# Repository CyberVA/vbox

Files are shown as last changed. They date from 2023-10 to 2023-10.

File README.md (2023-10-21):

# VBox: Low profile hitbox-layout fightstick

This repository is a fork of jfedor2's Flatbox project. Their original files are located in this repo [here](jfedor2_files).
You can also check our their repository [here](https://github.com/jfedor2/flatbox)

Changes from the original flatbox_rev4:
- Added RGB.
- Added OLED
- Relocated RP2040 and other various components for cosmetic reasons.

## PCB Image:

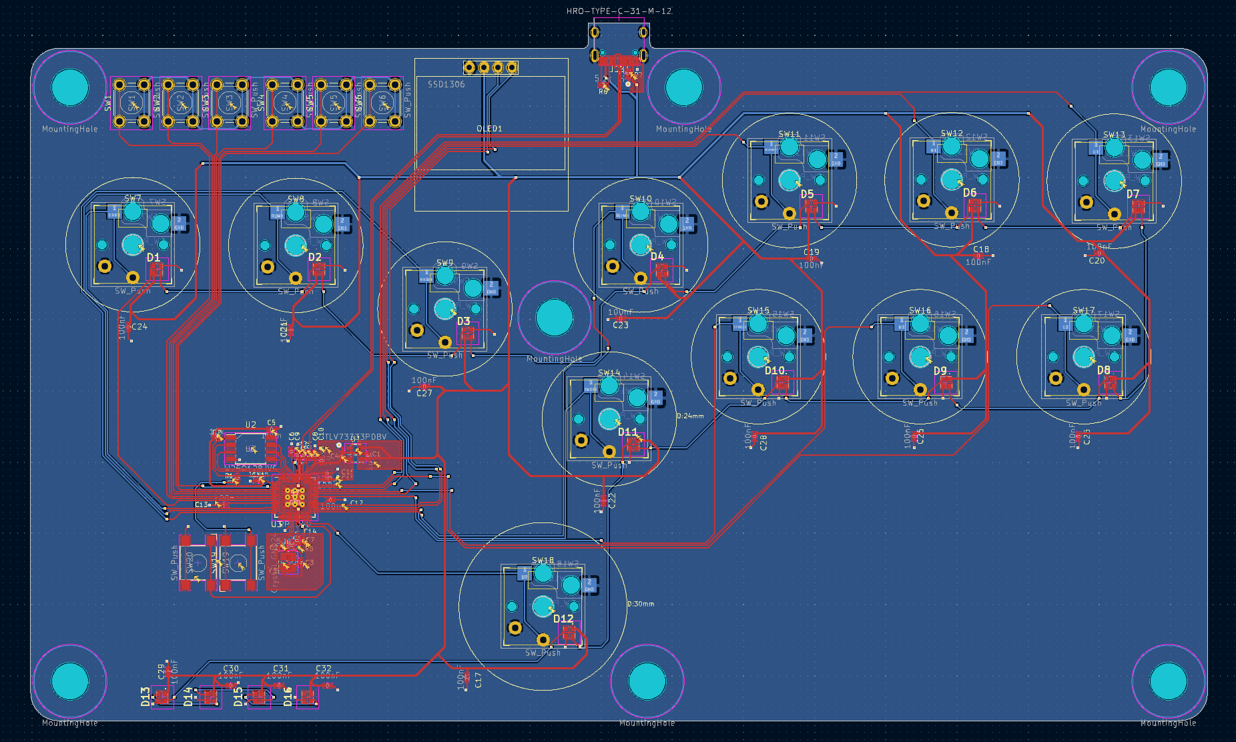
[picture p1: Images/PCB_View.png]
PCB View


## Schematic Images:

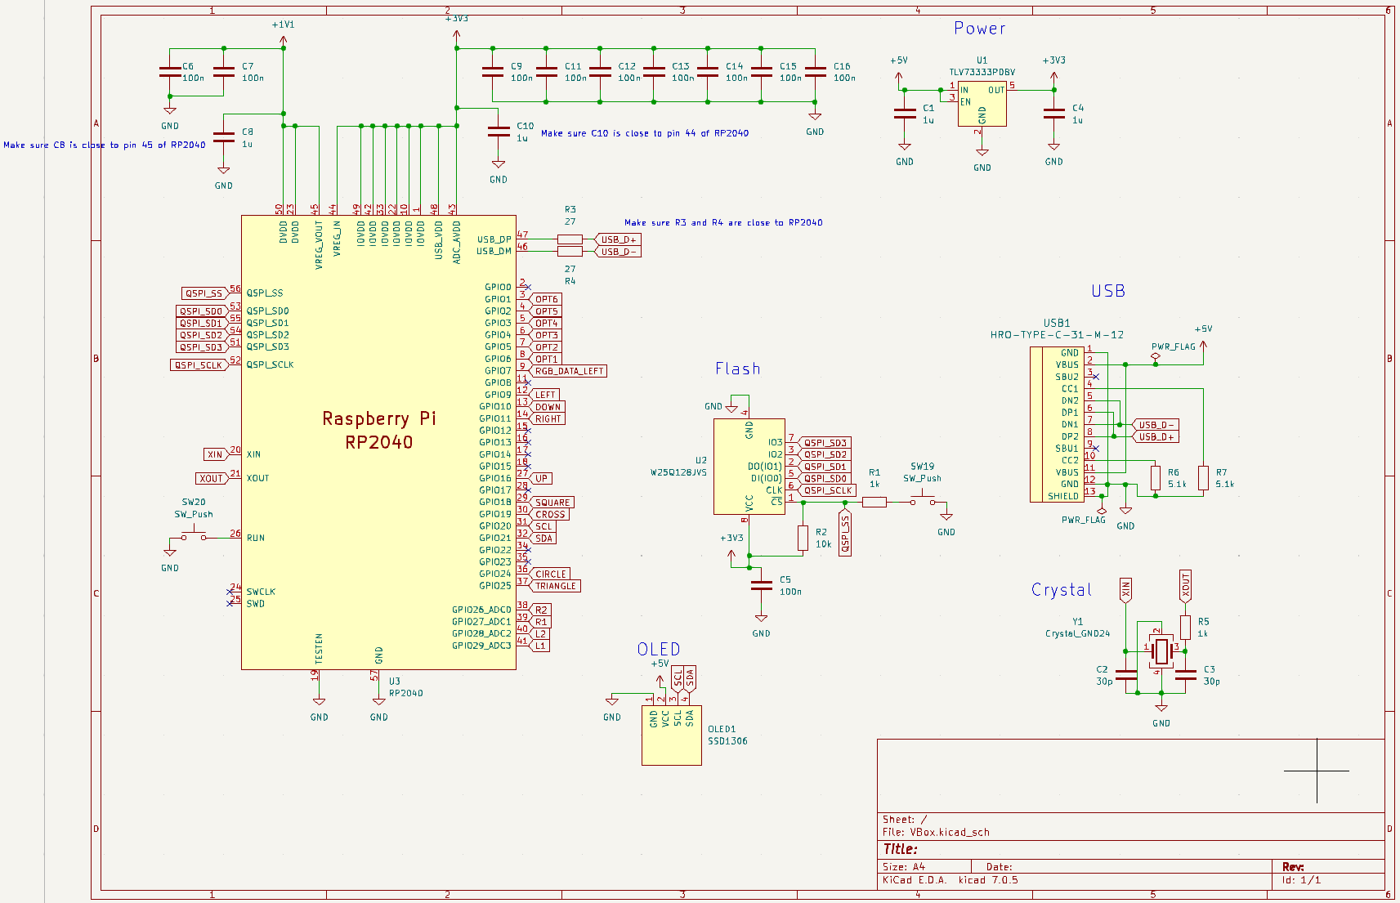
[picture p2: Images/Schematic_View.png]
Schematic


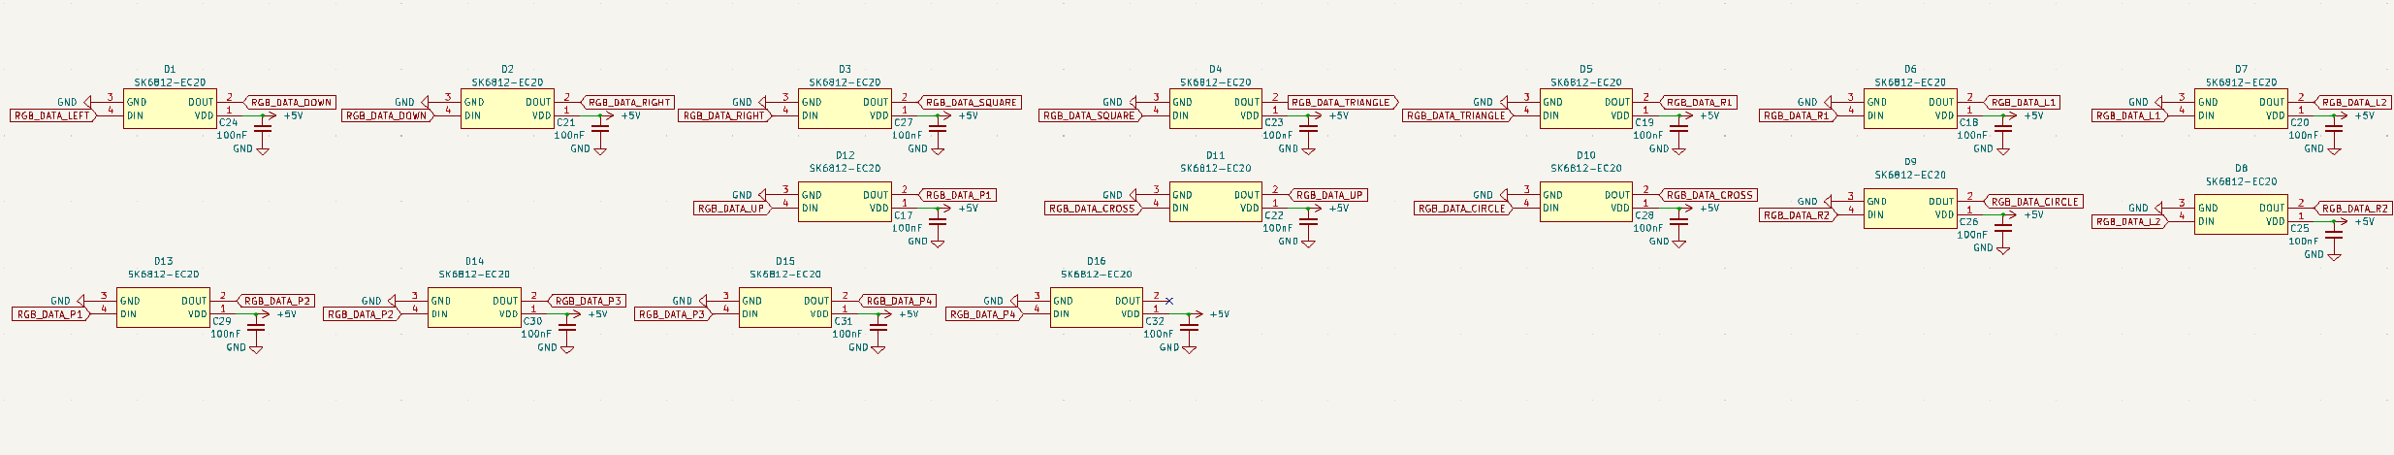
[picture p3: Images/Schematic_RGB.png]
Schematic RGB


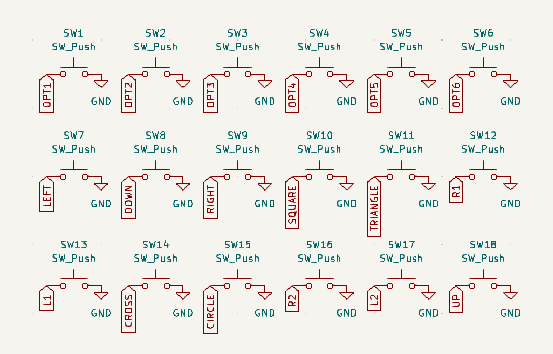
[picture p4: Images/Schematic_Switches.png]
Schematic Switches


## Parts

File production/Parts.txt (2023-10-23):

List of parts that cannot be placed by JLCPCB

Kailh PG1350 optional Hot Swap Sockets: https://chosfox.com/products/kailh-choc-switch-1350-hot-swap-sockets
 Sells for $1.45 for a pack of 10

SSD1306 I2C OLED: https://www.amazon.com/Dorhea-Display-SSD1306-Self-Luminous-Raspberry/dp/B0837DLWVH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
 Sells for $17.99 for a pack of 6

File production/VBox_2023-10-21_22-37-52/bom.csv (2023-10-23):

Designator | Footprint | Quantity | Value | LCSC Part #
C1, C10, C4, C8 | 0402 | 4 | 1u
C11, C12, C13, C14, C15, C16, C5, C6, C7, C9 | 0402 | 10 | 100n
C17, C18, C19, C20, C21, C22, C23, C24, C25, C26, C27, C28, C29, C30, C31, C32 | 0402 | 16 | 100nF | C52923
C2, C3 | 0402 | 2 | 30p
D1, D10, D11, D12, D13, D14, D15, D16, D2, D3, D4, D5, D6, D7, D8, D9 | SK6812EC20 | 16 | SK6812-EC20
H1, H2, H3, H4, H5, H6, H7 | MountingHole_6.4mm_M6 | 7 | MountingHole
OLED1 | 128x64OLED | 1 | SSD1306
R1, R5 | 0402 | 2 | 1k
R2 | 0402 | 1 | 10k
R3, R4 | 0402 | 2 | 27
R6, R7 | 0402 | 2 | 5.1k
SW1, SW2, SW3, SW4, SW5, SW6 | SW_PUSH_6mm_H5mm | 6 | SW_Push
SW10, SW11, SW12, SW13, SW14, SW15, SW16, SW17, SW18, SW7, SW8, SW9 | Kailh_socket_PG1350_optional | 12 | SW_Push
SW19, SW20 | SW_SPST_Omron_B3FS-100xP | 2 | SW_Push
U1 | SOT-23-5 | 1 | TLV73333PDBV
U2 | SOIC-8_5.23x5.23mm_P1.27mm | 1 | W25Q128JVS
U3 | RP2040-QFN-56 | 1 | RP2040
USB1 | HRO-TYPE-C-31-M-12-Assembly | 1 | HRO-TYPE-C-31-M-12
Y1 | Crystal_SMD_3225-4Pin_3.2x2.5mm | 1 | Crystal_GND24

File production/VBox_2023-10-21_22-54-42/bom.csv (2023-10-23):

Designator | Footprint | Quantity | Value | LCSC Part #
C1, C10, C4, C8 | 0402 | 4 | 1uF | C52923
C11, C12, C13, C14, C15, C16, C5, C6, C7, C9 | 0402 | 10 | 100nF | C1525
C17, C18, C19, C20, C21, C22, C23, C24, C25, C26, C27, C28, C29, C30, C31, C32 | 0402 | 16 | 100nF | C1525
C2, C3 | 0402 | 2 | 30pF | C1570
D1, D10, D11, D12, D13, D14, D15, D16, D2, D3, D4, D5, D6, D7, D8, D9 | SK6812EC20 | 16 | SK6812-EC20 | C2909058
OLED1 | 128x64OLED | 1 | SSD1306
R1, R5 | 0402 | 2 | 1k | C11702
R2 | 0402 | 1 | 10k | C25744
R3, R4 | 0402 | 2 | 27k | C138021
R6, R7 | 0402 | 2 | 5.1k | C25905
SW1, SW2, SW3, SW4, SW5, SW6 | SW_PUSH_6mm_H5mm | 6 | SW_Push | C428628
SW10, SW11, SW12, SW13, SW14, SW15, SW16, SW17, SW18, SW7, SW8, SW9 | Kailh_socket_PG1350_optional | 12 | SW_Push
SW19, SW20 | SW_SPST_Omron_B3FS-100xP | 2 | SW_Push | C271750
U1 | SOT-23-5 | 1 | TLV73333PDBV | C134139
U2 | SOIC-8_5.23x5.23mm_P1.27mm | 1 | W25Q128JVS | C97521
U3 | RP2040-QFN-56 | 1 | RP2040 | C2040
USB1 | HRO-TYPE-C-31-M-12-Assembly | 1 | HRO-TYPE-C-31-M-12 | C165948
Y1 | Crystal_SMD_3225-4Pin_3.2x2.5mm | 1 | Crystal_GND24 | C9002

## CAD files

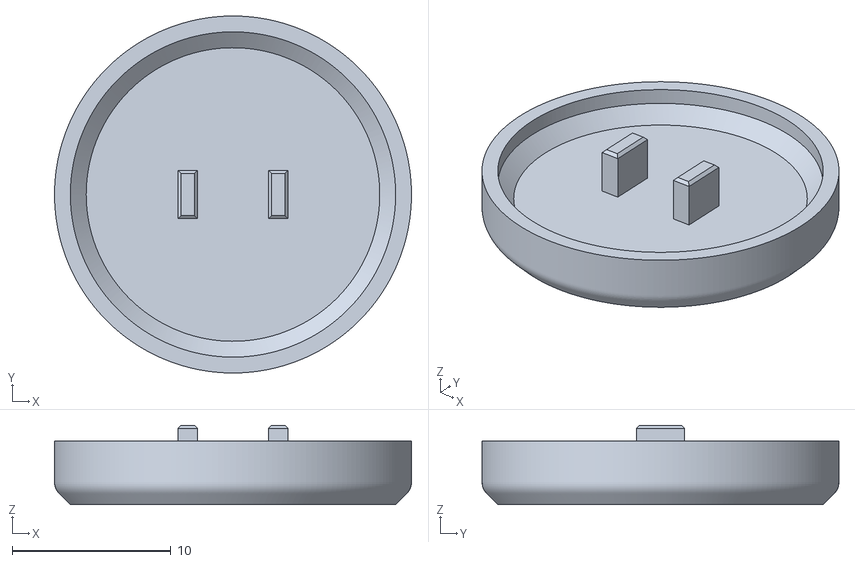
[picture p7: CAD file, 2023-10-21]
jfedor2_files/3d-printed-buttoncaps/Buttoncap.stl
22.5 x 22.5 x 5.00

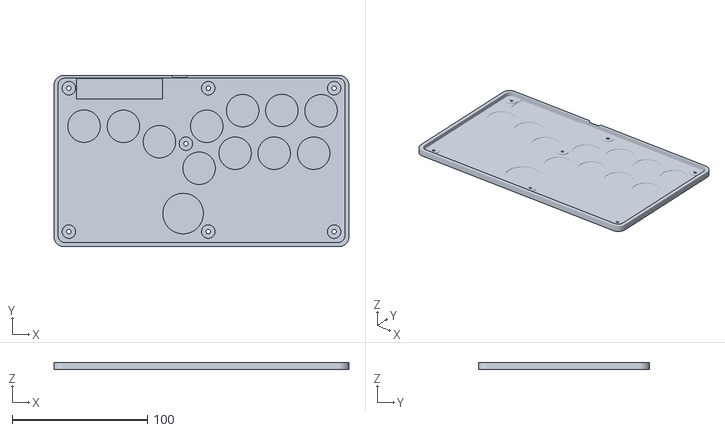
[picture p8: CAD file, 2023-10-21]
jfedor2_files/hardware-rev5/3d-printed-case/Flatbox-rev5-Bottom.stl
218.0 x 126.4 x 5.20

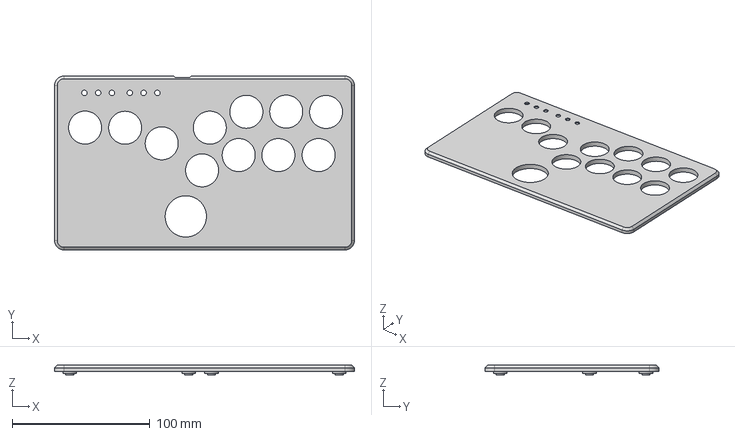
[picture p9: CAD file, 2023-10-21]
jfedor2_files/hardware-rev5/cnc-machined-case/Flatbox-rev5-CNC-Top.step
218.0 x 126.4 x 7.20 mm

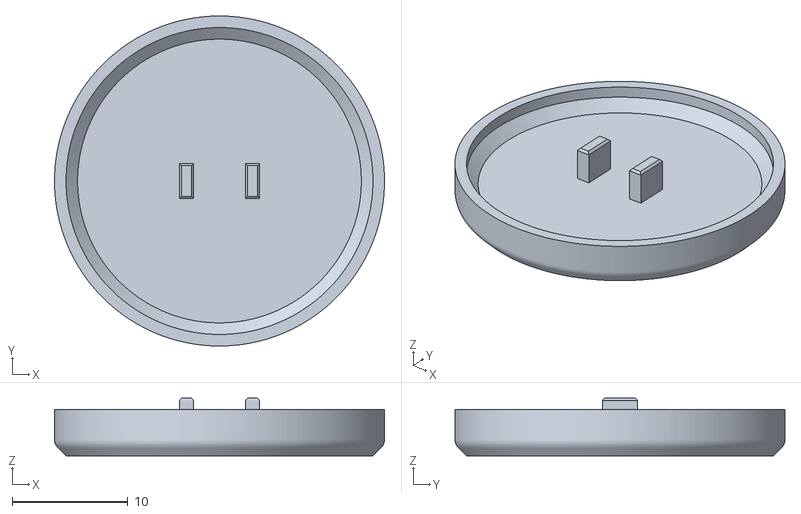
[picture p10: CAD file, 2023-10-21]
jfedor2_files/3d-printed-buttoncaps/ButtoncapBig.stl
28.5 x 28.5 x 5.00

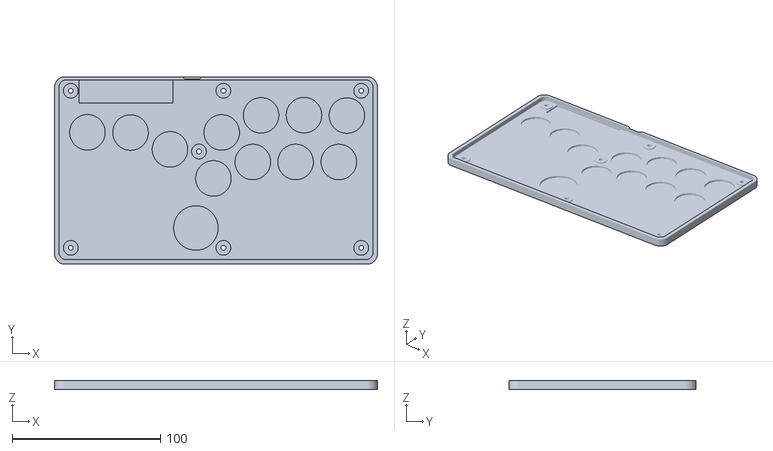
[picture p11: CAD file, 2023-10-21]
jfedor2_files/hardware-rev5/3d-printed-case/Flatbox-rev5-Bottom-hotswap.stl
218.0 x 126.4 x 6.20

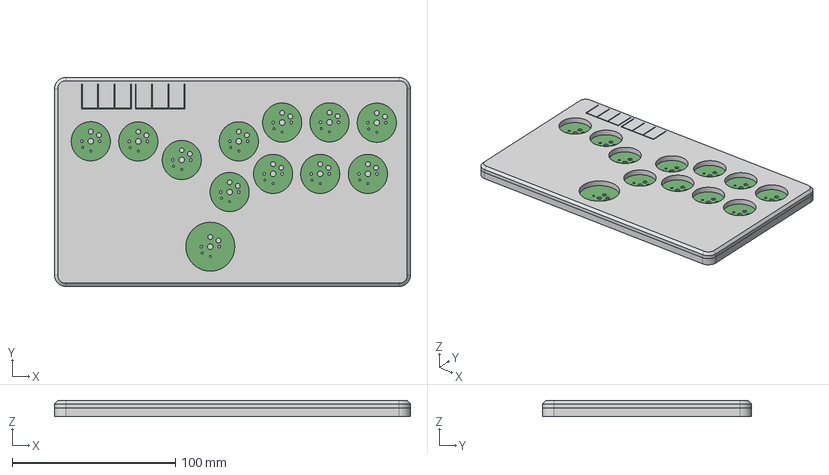
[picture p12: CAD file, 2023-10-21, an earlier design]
jfedor2_files/hardware-rev1.1/extras/Flatbox-rev1.1-case.step
218.0 x 128.0 x 9.80 mm

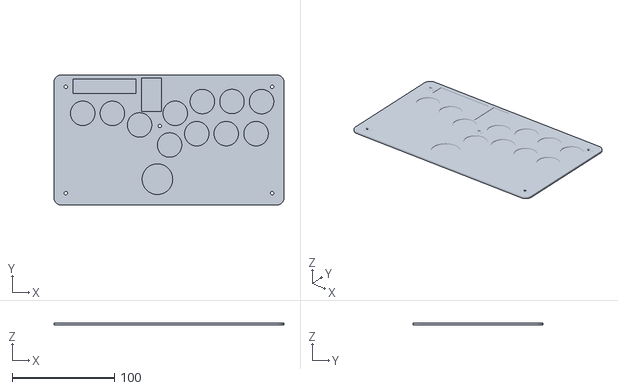
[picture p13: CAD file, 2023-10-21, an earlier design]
jfedor2_files/hardware-rev1/3d-printed-case/Flatbox-rev1b-Bottom.stl
225.2 x 127.4 x 2.20

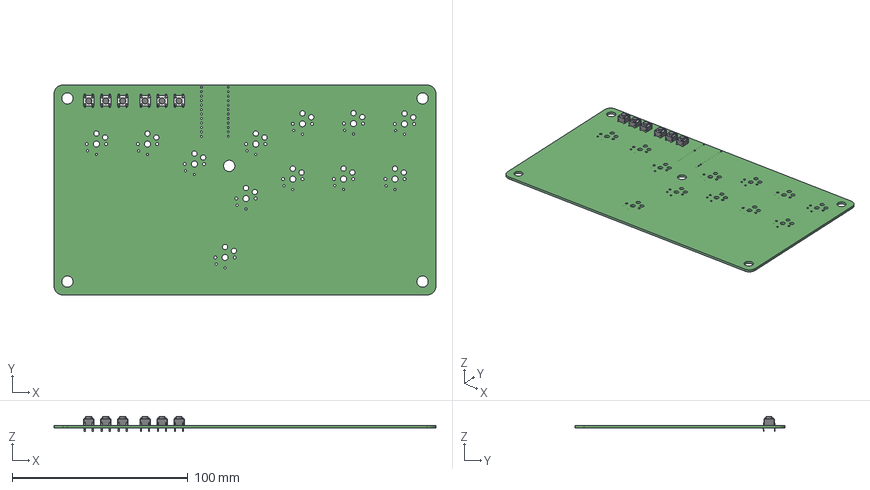
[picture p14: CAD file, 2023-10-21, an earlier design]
jfedor2_files/hardware-rev1/extras/Flatbox-rev1b-pcb.step
217.2 x 119.4 x 8.50 mm

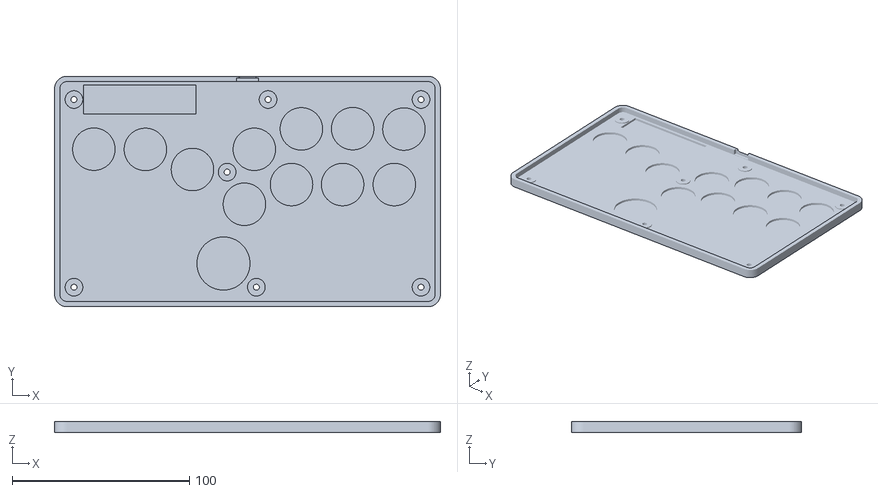
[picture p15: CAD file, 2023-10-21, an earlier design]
jfedor2_files/hardware-rev2/3d-printed-case/Flatbox-rev2b-Bottom-hotswap.stl
218.0 x 130.1 x 6.20

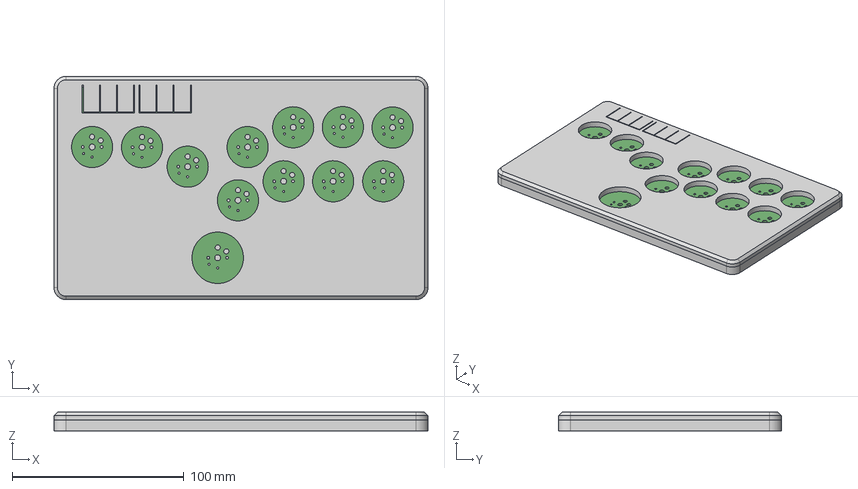
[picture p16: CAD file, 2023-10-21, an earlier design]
jfedor2_files/hardware-rev2/extras/Flatbox-rev2b-case-hotswap.step
218.0 x 130.1 x 10.8 mm

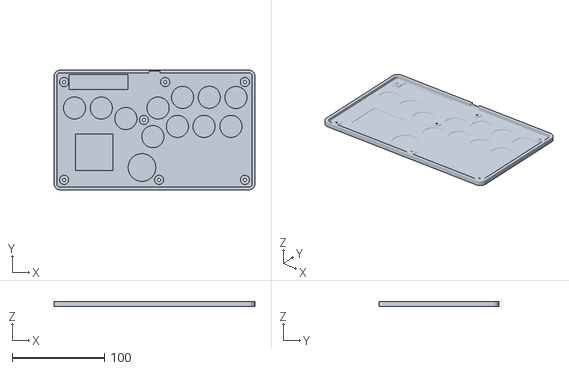
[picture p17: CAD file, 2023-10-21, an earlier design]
jfedor2_files/hardware-rev3/3d-printed-case/Flatbox-rev3-Bottom.stl
218.0 x 130.1 x 5.20

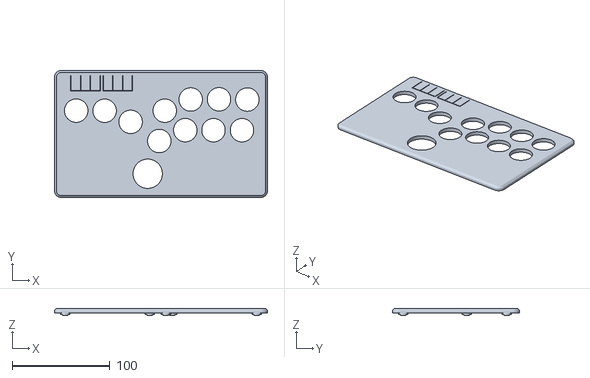
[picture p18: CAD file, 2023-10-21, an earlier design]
jfedor2_files/hardware-rev4/3d-printed-case/Flatbox-rev4-Top.stl
218.0 x 130.1 x 7.20

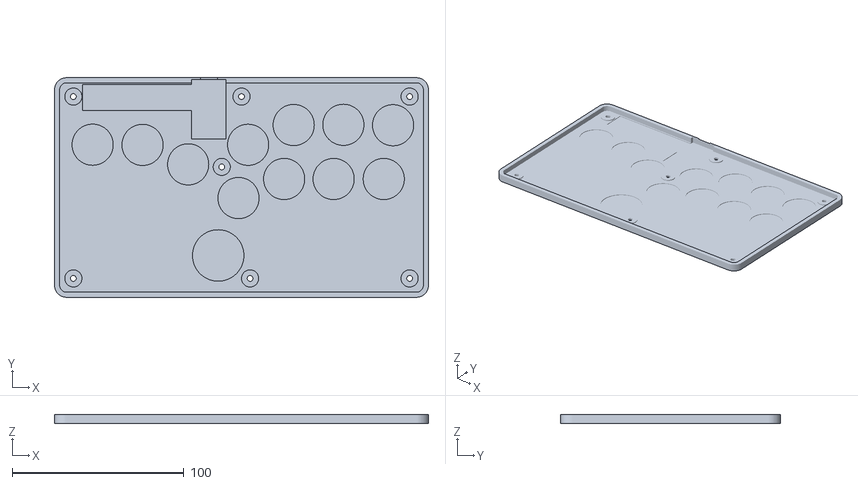
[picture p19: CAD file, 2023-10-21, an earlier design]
jfedor2_files/hardware-rev1.1/3d-printed-case/Flatbox-rev1.1-Bottom.stl
218.0 x 128.0 x 5.20

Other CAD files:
jfedor2_files/hardware-rev5/cnc-machined-case/Flatbox-rev5-CNC-Bottom.step
jfedor2_files/hardware-rev5/3d-printed-case/Flatbox-rev5-Top.stl
jfedor2_files/hardware-rev1.1/3d-printed-case/Flatbox-rev1.1-Top.stl
jfedor2_files/hardware-rev3/extras/Flatbox-rev3-case-hotswap.step
jfedor2_files/hardware-rev4/extras/Flatbox-rev4-case-hotswap.step
jfedor2_files/hardware-rev1.1/3d-printed-case/Flatbox-rev1.1-Bottom-hotswap.stl
jfedor2_files/hardware-rev1.1/extras/Flatbox-rev1.1-case-hotswap.step
jfedor2_files/hardware-rev1.1/extras/Flatbox-rev1.1-pcb.step
jfedor2_files/hardware-rev1/3d-printed-case/Flatbox-rev1b-Bottom-hotswap.stl
jfedor2_files/hardware-rev1/3d-printed-case/Flatbox-rev1b-Top.stl
jfedor2_files/hardware-rev2/3d-printed-case/Flatbox-rev2b-Bottom.stl
jfedor2_files/hardware-rev2/3d-printed-case/Flatbox-rev2b-Top.stl
jfedor2_files/hardware-rev2/extras/Flatbox-rev2b-case.step
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

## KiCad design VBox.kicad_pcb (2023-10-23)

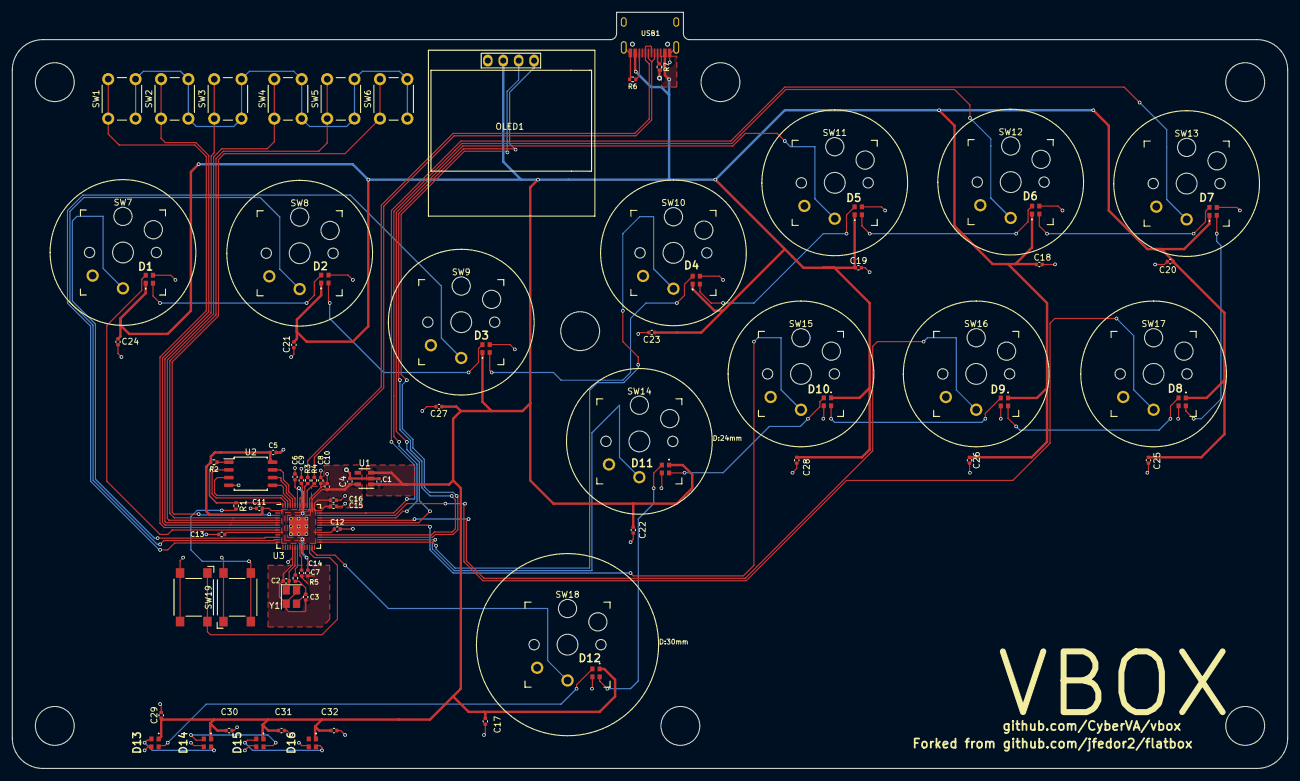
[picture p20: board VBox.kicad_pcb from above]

Board: 2 copper layers, 210.0 x 124.5 mm, 88 parts (0 on the bottom side), 57 nets.

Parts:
C1, C4, C8, C10: 1uF; C_0402_1005Metric
C2, C3: 30pF; C_0402_1005Metric
C5, C6, C7, C9, C11, C12, C13, C14, C15, C16, C17, C18, C19, C20, C21, C22, C23, C24, C25, C26, C27, C28, C29, C30, C31, C32: 100nF; C_0402_1005Metric
D1, D2, D3, D4, D5, D6, D7, D8, D9, D10, D11, D12, D13, D14, D15, D16: SK6812-EC20; SK6812EC20
H1, H2, H3, H4, H5, H6, H7: MountingHole; MountingHole_6.4mm_M6
OLED1: SSD1306; 128x64OLED
R1, R5: 1k; R_0402_1005Metric
R2: 10k; R_0402_1005Metric
R3, R4: 27; R_0402_1005Metric
R6, R7: 5.1k; R_0402_1005Metric
SW1, SW2, SW3, SW4, SW5, SW6: SW_Push; SW_PUSH_6mm_H5mm
SW7, SW8, SW9, SW10, SW11, SW12, SW13, SW14, SW15, SW16, SW17, SW18: SW_Push; Kailh_socket_PG1350_optional
SW19, SW20: SW_Push; SW_SPST_Omron_B3FS-100xP
U1: TLV73333PDBV; SOT-23-5
U2: W25Q128JVS; SOIC-8_5.23x5.23mm_P1.27mm
U3: RP2040; RP2040-QFN-56
USB1: HRO-TYPE-C-31-M-12; HRO-TYPE-C-31-M-12-Assembly
Y1: Crystal_GND24; Crystal_SMD_3225-4Pin_3.2x2.5mm

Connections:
+1V1: C6.1, C7.1, C8.1, U3.23 (DVDD), U3.45 (VREG_VOUT), U3.50 (DVDD)
+3V3: C4.1, C5.1, C9.1, C10.1, C11.1, C12.1, C13.1, C14.1, C15.1, C16.1, R2.2, U1.5 (OUT), U2.8 (VCC), U3.1 (IOVDD), U3.10 (IOVDD), U3.22 (IOVDD), U3.33 (IOVDD), U3.42 (IOVDD), U3.43 (ADC_AVDD), U3.44 (VREG_IN), U3.48 (USB_VDD), U3.49 (IOVDD)
+5V: C1.1, C17.1, C18.1, C19.1, C20.1, C21.1, C22.1, C23.1, C24.1, C25.1, C26.1, C27.1, C28.1, C29.1, C30.1, C31.1, C32.1, D1.1 (VDD), D2.1 (VDD), D3.1 (VDD), D4.1 (VDD), D5.1 (VDD), D6.1 (VDD), D7.1 (VDD), D8.1 (VDD), D9.1 (VDD), D10.1 (VDD), D11.1 (VDD), D12.1 (VDD), D13.1 (VDD), D14.1 (VDD), D15.1 (VDD), D16.1 (VDD), OLED1.2 (VCC), U1.1 (IN), U1.3 (EN), USB1.2 (VBUS), USB1.11 (VBUS)
CIRCLE: SW15.1, U3.36 (GPIO24)
CROSS: SW14.1, U3.30 (GPIO19)
DOWN: SW8.1, U3.13 (GPIO10)
GND: C1.2, C2.2, C3.2, C4.2, C5.2, C6.2, C7.2, C8.2, C9.2, C10.2, C11.2, C12.2, C13.2, C14.2, C15.2, C16.2, C17.2, C18.2, C19.2, C20.2, C21.2, C22.2, C23.2, C24.2, C25.2, C26.2, C27.2, C28.2, C29.2, C30.2, C31.2, C32.2, D1.3 (GND), D2.3 (GND), D3.3 (GND), D4.3 (GND), D5.3 (GND), D6.3 (GND), D7.3 (GND), D8.3 (GND), D9.3 (GND), D10.3 (GND), D11.3 (GND), D12.3 (GND), D13.3 (GND), D14.3 (GND), D15.3 (GND), D16.3 (GND), OLED1.1 (GND), R6.2, R7.2, SW1.2, SW2.2, SW3.2, SW4.2, SW5.2, SW6.2, SW7.2, SW8.2, SW9.2, SW10.2, SW11.2, SW12.2, SW13.2, SW14.2, SW15.2, SW16.2, SW17.2, SW18.2, SW19.2, SW20.1, U1.2 (GND), U2.4 (GND), U3.19 (TESTEN), U3.57 (GND), USB1.1 (GND), USB1.12 (GND), USB1.13 (SHIELD), Y1.2, Y1.4
L1: SW13.1, U3.41 (GPIO29_ADC3)
L2: SW17.1, U3.40 (GPIO28_ADC2)
LEFT: SW7.1, U3.12 (GPIO9)
unnamed: C3.1, R5.2, Y1.3
unnamed: R1.2, SW19.1
unnamed: SW20.2, U3.26 (RUN)
unnamed: R4.1, U3.46 (USB_DM)
unnamed: R3.1, U3.47 (USB_DP)
unnamed: R7.1, USB1.4 (CC1)
unnamed: R6.1, USB1.10 (CC2)
OPT1: SW1.1, U3.8 (GPIO6)
OPT2: SW2.1, U3.7 (GPIO5)
OPT3: SW3.1, U3.6 (GPIO4)
OPT4: SW4.1, U3.5 (GPIO3)
OPT5: SW5.1, U3.4 (GPIO2)
OPT6: SW6.1, U3.3 (GPIO1)
QSPI_SCLK: U2.6 (CLK), U3.52 (QSPI_SCLK)
QSPI_SD0: U2.5 (DI(IO0)), U3.53 (QSPI_SD0)
QSPI_SD1: U2.2 (DO(IO1)), U3.55 (QSPI_SD1)
QSPI_SD2: U2.3 (IO2), U3.54 (QSPI_SD2)
QSPI_SD3: U2.7 (IO3), U3.51 (QSPI_SD3)
QSPI_SS: R1.1, R2.1, U2.1 (~CS), U3.56 (QSPI_SS)
R1: SW12.1, U3.39 (GPIO27_ADC1)
R2: SW16.1, U3.38 (GPIO26_ADC0)
RGB_DATA_CIRCLE: D9.2 (DOUT), D10.4 (DIN)
RGB_DATA_CROSS: D10.2 (DOUT), D11.4 (DIN)
RGB_DATA_DOWN: D1.2 (DOUT), D2.4 (DIN)
RGB_DATA_L1: D6.2 (DOUT), D7.4 (DIN)
RGB_DATA_L2: D7.2 (DOUT), D8.4 (DIN)
RGB_DATA_LEFT: D1.4 (DIN), U3.9 (GPIO7)
RGB_DATA_P1: D12.2 (DOUT), D13.4 (DIN)
RGB_DATA_P2: D13.2 (DOUT), D14.4 (DIN)
RGB_DATA_P3: D14.2 (DOUT), D15.4 (DIN)
RGB_DATA_P4: D15.2 (DOUT), D16.4 (DIN)
RGB_DATA_R1: D5.2 (DOUT), D6.4 (DIN)
RGB_DATA_R2: D8.2 (DOUT), D9.4 (DIN)
RGB_DATA_RIGHT: D2.2 (DOUT), D3.4 (DIN)
RGB_DATA_SQUARE: D3.2 (DOUT), D4.4 (DIN)
RGB_DATA_TRIANGLE: D4.2 (DOUT), D5.4 (DIN)
RGB_DATA_UP: D11.2 (DOUT), D12.4 (DIN)
RIGHT: SW9.1, U3.14 (GPIO11)
SCL: OLED1.3 (SCL), U3.31 (GPIO20)
SDA: OLED1.4 (SDA), U3.32 (GPIO21)
SQUARE: SW10.1, U3.29 (GPIO18)
TRIANGLE: SW11.1, U3.37 (GPIO25)
UP: SW18.1, U3.27 (GPIO16)
USB_D+: R3.2, USB1.6 (DP1), USB1.8 (DP2)
USB_D-: R4.2, USB1.5 (DN2), USB1.7 (DN1)
XIN: C2.1, U3.20 (XIN), Y1.1
XOUT: R5.1, U3.21 (XOUT)

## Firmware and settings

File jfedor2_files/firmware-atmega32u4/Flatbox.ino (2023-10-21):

// Jacek Fedorynski <jfedor@jfedor.org>
// http://www.jfedor.org/

// Uncomment the appropriate line to match your stick version
#define REV1
//#define REV2

#include "HID.h"

#ifdef REV1

#define PIN_UP        9
#define PIN_DOWN      7
#define PIN_LEFT      6
#define PIN_RIGHT     8
#define PIN_CROSS     10
#define PIN_CIRCLE    14
#define PIN_TRIANGLE  15
#define PIN_SQUARE    16
#define PIN_L1        21
#define PIN_L2        20
#define PIN_R1        19
#define PIN_R2        18
#define PIN_SELECT    2
#define PIN_START     1
#define PIN_L3        5
#define PIN_R3        3
#define PIN_PS        0

#endif

#ifdef REV2

#define PIN_UP        5
#define PIN_DOWN      9
#define PIN_LEFT      8
#define PIN_RIGHT     10
#define PIN_CROSS     18
#define PIN_CIRCLE    21
#define PIN_TRIANGLE  14
#define PIN_SQUARE    7
#define PIN_L1        15
#define PIN_L2        19
#define PIN_R1        16
#define PIN_R2        20
#define PIN_SELECT    1
#define PIN_START     4
#define PIN_L3        3
#define PIN_R3        0
#define PIN_PS        6

#endif

int stickMode = 0; // 0 = dpad, 1 = left stick

// HID report descriptor taken from a HORI Fighting Stick V3
// works out of the box with PC and PS3
// as dumped by usbhid-dump and parsed by https://eleccelerator.com/usbdescreqparser/
static const uint8_t hidReportDescriptor[] PROGMEM = {
  0x05, 0x01,        // Usage Page (Generic Desktop Ctrls)
  0x09, 0x05,        // Usage (Game Pad)
  0xA1, 0x01,        // Collection (Application)
  0x85, 0x01,        // Report ID, not in the original descriptor, but the Arduino HID library can't seem to live without it
  0x15, 0x00,        //   Logical Minimum (0)
  0x25, 0x01,        //   Logical Maximum (1)
  0x35, 0x00,        //   Physical Minimum (0)
  0x45, 0x01,        //   Physical Maximum (1)
  0x75, 0x01,        //   Report Size (1)
  0x95, 0x0D,        //   Report Count (13)
  0x05, 0x09,        //   Usage Page (Button)
  0x19, 0x01,        //   Usage Minimum (0x01)
  0x29, 0x0D,        //   Usage Maximum (0x0D)
  0x81, 0x02,        //   Input (Data,Var,Abs,No Wrap,Linear,Preferred State,No Null Position)
  0x95, 0x03,        //   Report Count (3)
  0x81, 0x01,        //   Input (Const,Array,Abs,No Wrap,Linear,Preferred State,No Null Position)
  0x05, 0x01,        //   Usage Page (Generic Desktop Ctrls)
  0x25, 0x07,        //   Logical Maximum (7)
  0x46, 0x3B, 0x01,  //   Physical Maximum (315)
  0x75, 0x04,        //   Report Size (4)
  0x95, 0x01,        //   Report Count (1)
  0x65, 0x14,        //   Unit (System: English Rotation, Length: Centimeter)
  0x09, 0x39,        //   Usage (Hat switch)
  0x81, 0x42,        //   Input (Data,Var,Abs,No Wrap,Linear,Preferred State,Null State)
  0x65, 0x00,        //   Unit (None)
  0x95, 0x01,        //   Report Count (1)
  0x81, 0x01,        //   Input (Const,Array,Abs,No Wrap,Linear,Preferred State,No Null Position)
  0x26, 0xFF, 0x00,  //   Logical Maximum (255)
  0x46, 0xFF, 0x00,  //   Physical Maximum (255)
  0x09, 0x30,        //   Usage (X)
  0x09, 0x31,        //   Usage (Y)
  0x09, 0x32,        //   Usage (Z)
  0x09, 0x35,        //   Usage (Rz)
  0x75, 0x08,        //   Report Size (8)
  0x95, 0x04,        //   Report Count (4)
  0x81, 0x02,        //   Input (Data,Var,Abs,No Wrap,Linear,Preferred State,No Null Position)
  0x06, 0x00, 0xFF,  //   Usage Page (Vendor Defined 0xFF00)
  0x09, 0x20,        //   Usage (0x20)
  0x09, 0x21,        //   Usage (0x21)
  0x09, 0x22,        //   Usage (0x22)
  0x09, 0x23,        //   Usage (0x23)
  0x09, 0x24,        //   Usage (0x24)
  0x09, 0x25,        //   Usage (0x25)
  0x09, 0x26,        //   Usage (0x26)
  0x09, 0x27,        //   Usage (0x27)
  0x09, 0x28,        //   Usage (0x28)
  0x09, 0x29,        //   Usage (0x29)
  0x09, 0x2A,        //   Usage (0x2A)
  0x09, 0x2B,        //   Usage (0x2B)
  0x95, 0x0C,        //   Report Count (12)
  0x81, 0x02,        //   Input (Data,Var,Abs,No Wrap,Linear,Preferred State,No Null Position)
  0x0A, 0x21, 0x26,  //   Usage (0x2621)
  0x95, 0x08,        //   Report Count (8)
  0xB1, 0x02,        //   Feature (Data,Var,Abs,No Wrap,Linear,Preferred State,No Null Position,Non-volatile)
  0x0A, 0x21, 0x26,  //   Usage (0x2621)
  0x91, 0x02,        //   Output (Data,Var,Abs,No Wrap,Linear,Preferred State,No Null Position,Non-volatile)
  0x26, 0xFF, 0x03,  //   Logical Maximum (1023)
  0x46, 0xFF, 0x03,  //   Physical Maximum (1023)
  0x09, 0x2C,        //   Usage (0x2C)
  0x09, 0x2D,        //   Usage (0x2D)
  0x09, 0x2E,        //   Usage (0x2E)
  0x09, 0x2F,        //   Usage (0x2F)
  0x75, 0x10,        //   Report Size (16)
  0x95, 0x04,        //   Report Count (4)
  0x81, 0x02,        //   Input (Data,Var,Abs,No Wrap,Linear,Preferred State,No Null Position)
  0xC0,              // End Collection
};

typedef struct {
  uint16_t buttons; // bits: 0 = square, 1 = cross, 2 = circle, 3 = triangle,
                    // 4 = L1, 5 = R1, 6 = L2, 7 = R2, 8 = select, 9 = start,
                    // 10 = L3, 11 = R3, 12 = PS
  uint8_t dpadHat; // 0 = up, 1 = up/right, 2 = right etc., 0x0f = neutral
  uint8_t leftStickXAxis;
  uint8_t leftStickYAxis;
  uint8_t rightStickXAxis;
  uint8_t rightStickYAxis;
  uint8_t dpadRightAxis;
  uint8_t dpadLeftAxis;
  uint8_t dpadUpAxis;
  uint8_t dpadDownAxis;
  uint8_t triangleAxis;
  uint8_t circleAxis;
  uint8_t crossAxis;
  uint8_t squareAxis;
  uint8_t L1Axis;
  uint8_t L2Axis;
  uint8_t R1Axis;
  uint8_t R2Axis;
  uint16_t accelerometerXAxis; // 10 bits (these are guesses BTW)
  uint16_t accelerometerYAxis; // 10 bits
  uint16_t accelerometerZAxis; // 10 bits
  uint16_t gyroscopeAxis; // 10 bits
} hid_report_t;

hid_report_t report;
hid_report_t prevReport;

void dpad(bool up, bool down, bool left, bool right) {
  if (up && down) {
    up = down = false;
  }
  if (left && right) {
    left = right = false;
  }

  switch (stickMode) {
    case 0:
      if (up && !right && !left) report.dpadHat = 0;
      else if (up && right) report.dpadHat = 1;
      else if (right && !up && !down) report.dpadHat = 2;
      else if (right && down) report.dpadHat = 3;
      else if (down && !right && !left) report.dpadHat = 4;
      else if (down && left) report.dpadHat = 5;
      else if (left && !down && !up) report.dpadHat = 6;
      else if (left && up) report.dpadHat = 7;
      else report.dpadHat = 0x0f;

      report.dpadRightAxis = right ? 0xff : 0x00;
      report.dpadLeftAxis = left ? 0xff : 0x00;
      report.dpadUpAxis = up ? 0xff : 0x00;
      report.dpadDownAxis = down ? 0xff : 0x00;
      break;
    case 1:
      report.leftStickXAxis = left ? 0x00 : (right ? 0xFF : 0x80);
      report.leftStickYAxis = up ? 0x00 : (down ? 0xFF : 0x80);
      break;
  }
}

void sendReport() {
  if (memcmp(&prevReport, &report, sizeof(report))) {
    HID().SendReport(1, &report, sizeof(report));
    memcpy(&prevReport, &report, sizeof(report));
  }
}

void setup() {
  static HIDSubDescriptor node(hidReportDescriptor, sizeof(hidReportDescriptor));
  HID().AppendDescriptor(&node);

  pinMode(PIN_UP, INPUT_PULLUP);
  pinMode(PIN_DOWN, INPUT_PULLUP);
  pinMode(PIN_LEFT, INPUT_PULLUP);
  pinMode(PIN_RIGHT, INPUT_PULLUP);
  pinMode(PIN_CROSS, INPUT_PULLUP);
  pinMode(PIN_CIRCLE, INPUT_PULLUP);
  pinMode(PIN_TRIANGLE, INPUT_PULLUP);
  pinMode(PIN_SQUARE, INPUT_PULLUP);
  pinMode(PIN_L1, INPUT_PULLUP);
  pinMode(PIN_L2, INPUT_PULLUP);
  pinMode(PIN_R1, INPUT_PULLUP);
  pinMode(PIN_R2, INPUT_PULLUP);
  pinMode(PIN_SELECT, INPUT_PULLUP);
  pinMode(PIN_START, INPUT_PULLUP);
  pinMode(PIN_L3, INPUT_PULLUP);
  pinMode(PIN_R3, INPUT_PULLUP);
  pinMode(PIN_PS, INPUT_PULLUP);

  // if left is held when plugged in, switch to left stick emulation mode
  if (digitalRead(PIN_LEFT) == LOW) {
    stickMode = 1;
  }

  memset(&report, 0, sizeof(report));
  report.dpadHat = 0x0f;
  report.accelerometerXAxis = 0x02; // not sure why 0x02, but that's what HORI Fighting Stick V3 sends
  report.accelerometerYAxis = 0x02;
  report.accelerometerZAxis = 0x02;
  report.gyroscopeAxis = 0x02;
  report.leftStickXAxis = 0x80;
  report.leftStickYAxis = 0x80;
  report.rightStickXAxis = 0x80;
  report.rightStickYAxis = 0x80;
  memcpy(&prevReport, &report, sizeof(report));
}

void loop() {
  report.buttons = 0x00;
  report.triangleAxis = 0x00;
  report.circleAxis = 0x00;
  report.crossAxis = 0x00;
  report.squareAxis = 0x00;
  report.L1Axis = 0x00;
  report.L2Axis = 0x00;
  report.R1Axis = 0x00;
  report.R2Axis = 0x00;

  dpad(digitalRead(PIN_UP) == LOW,
       digitalRead(PIN_DOWN) == LOW,
       digitalRead(PIN_LEFT) == LOW,
       digitalRead(PIN_RIGHT) == LOW);

  if (digitalRead(PIN_SQUARE) == LOW) {
    report.buttons |= 1 << 0;
    report.squareAxis = 0xff;
  }
  if (digitalRead(PIN_CROSS) == LOW) {
    report.buttons |= 1 << 1;
    report.crossAxis = 0xff;
  }
  if (digitalRead(PIN_CIRCLE) == LOW) {
    report.buttons |= 1 << 2;
    report.circleAxis = 0xff;
  }
  if (digitalRead(PIN_TRIANGLE) == LOW) {
    report.buttons |= 1 << 3;
    report.triangleAxis = 0xff;
  }
  if (digitalRead(PIN_L1) == LOW) {
    report.buttons |= 1 << 4;
    report.L1Axis = 0xff;
  }
  if (digitalRead(PIN_R1) == LOW) {
    report.buttons |= 1 << 5;
    report.R1Axis = 0xff;
  }
  if (digitalRead(PIN_L2) == LOW) {
    report.buttons |= 1 << 6;
    report.L2Axis = 0xff;
  }
  if (digitalRead(PIN_R2) == LOW) {
    report.buttons |= 1 << 7;
    report.R2Axis = 0xff;
  }
  if (digitalRead(PIN_SELECT) == LOW) {
    report.buttons |= 1 << 8;
  }
  if (digitalRead(PIN_START) == LOW) {
    report.buttons |= 1 << 9;
  }
  if (digitalRead(PIN_L3) == LOW) {
    report.buttons |= 1 << 10;
  }
  if (digitalRead(PIN_R3) == LOW) {
    report.buttons |= 1 << 11;
  }
  if (digitalRead(PIN_PS) == LOW) {
    report.buttons |= 1 << 12;
  }

  sendReport();
}

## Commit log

2023-10-21 Reorganization and addition of my own files
    [Buttoncap.stl, ButtoncapBig.stl, Flatbox-rev1.1-Bottom-hotswap.stl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]
2023-10-23 Production files, Gerbers, and adjustments
    [VBox-B_Cu.gbr, VBox-B_Mask.gbr, VBox-B_Paste.gbr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]
